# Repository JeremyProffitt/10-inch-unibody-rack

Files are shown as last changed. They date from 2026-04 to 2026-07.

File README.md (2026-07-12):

# 10-Inch Unibody Server Rack

A parametric, unibody 10-inch server rack designed to 3D print in a single piece on the **Bambu Labs H2D**. Prints front-face-down with **zero supports required**.

## Features

- **6U capacity** with standard EIA-310 mounting hole pattern
- **Prints in one piece** - no assembly required
- **No supports needed** - all geometry is self-supporting when printed face-down
- **Rounded exterior edges** for clean aesthetics and handling comfort
- **M6 nut traps** with diamond bevels for captive hardware
- **Grip bars** and filleted handle cutouts for comfortable carrying
- **Open back** for ventilation and cable management
- **Parametric design** - easily adjust rack units, depth, wall thickness
- **LCD + Raspberry Pi cases** in single/dual landscape and portrait layouts
- **Parametric viewing angle** with enclosure depth derived from the chosen angle

## Designs

### Just a Rack (6U)

| Front View | Rear View |
|---|---|
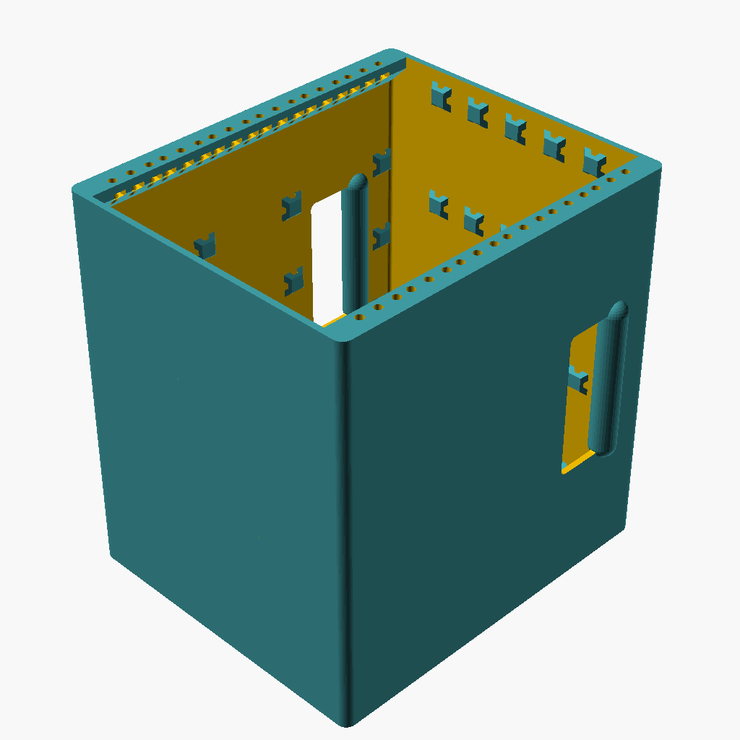
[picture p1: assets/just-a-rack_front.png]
Front
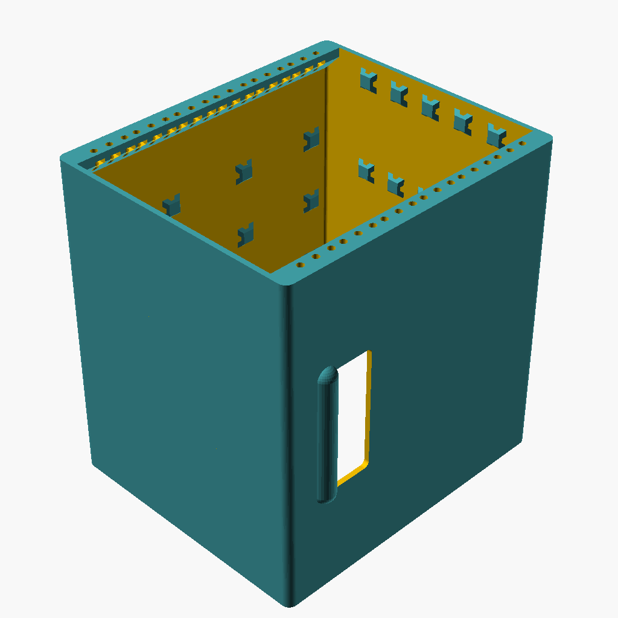
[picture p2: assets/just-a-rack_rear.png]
Rear
|  |  |

Unibody 6U 10-inch server rack with M6 nut traps, 18mm grip bars, filleted handle cutouts, and 30mm deep mounting rails. Prints support-free on the Bambu Labs H2D.

**Download STL**: [just-a-rack.stl](https://github.com/JeremyProffitt/10-inch-unibody-rack/releases/latest/download/just-a-rack.stl)

### Just a Rack with Pocket (6U)

| Front View | Rear View |
|---|---|
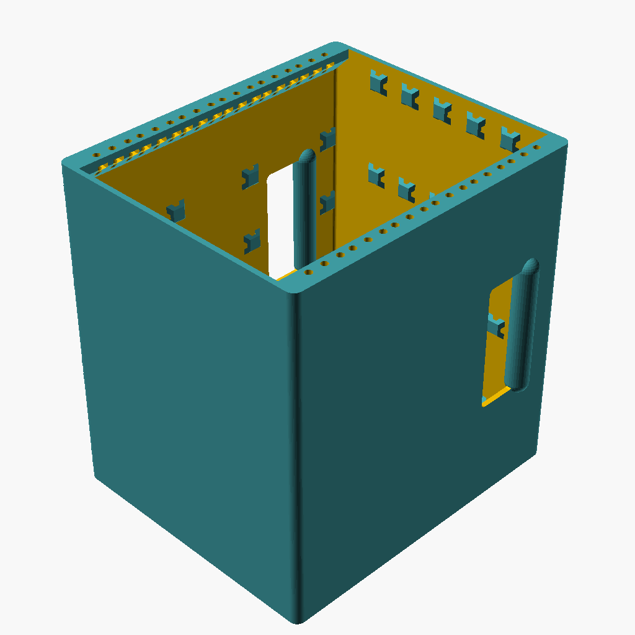
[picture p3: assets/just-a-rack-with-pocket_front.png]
Front
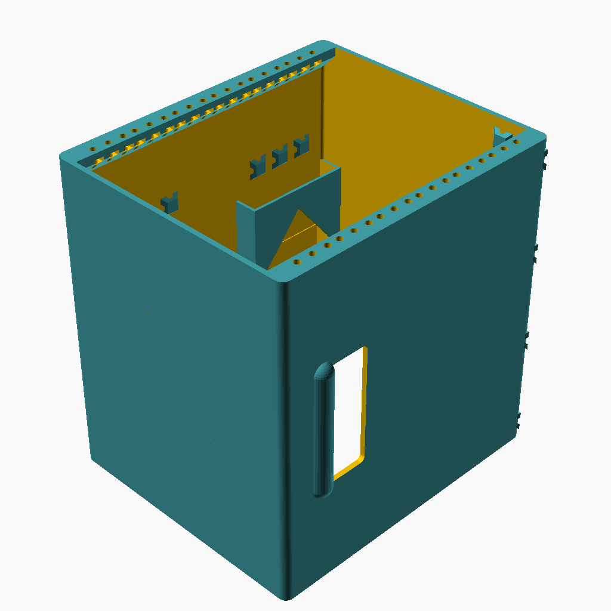
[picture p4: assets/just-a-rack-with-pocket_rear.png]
Rear
|  |  |

Same rack with a USW Flex Mini pocket on the right interior wall. Includes a 45-degree support ramp and triangular cable routing cutout for support-free printing.

**Download STL**: [just-a-rack-with-pocket.stl](https://github.com/JeremyProffitt/10-inch-unibody-rack/releases/latest/download/just-a-rack-with-pocket.stl)

### Rack with Cubbies (6U)

| Front View | Rear View |
|---|---|
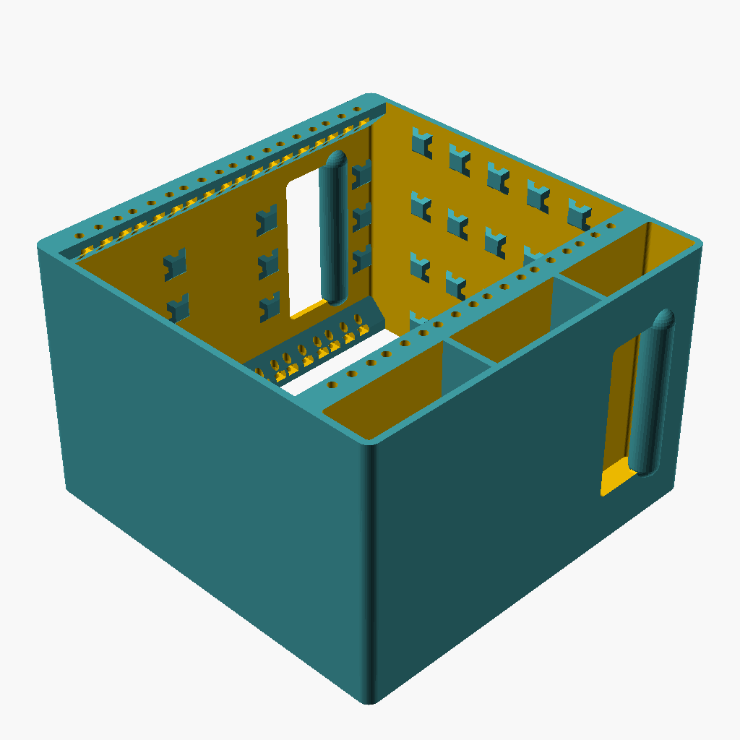
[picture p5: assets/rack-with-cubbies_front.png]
Front
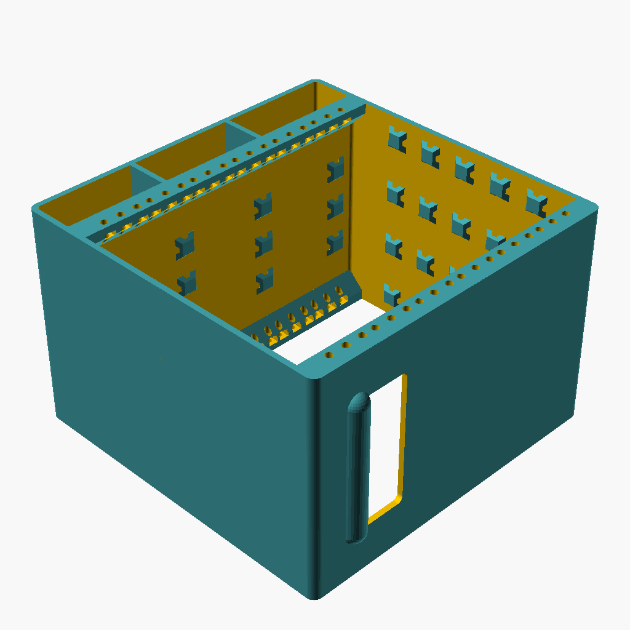
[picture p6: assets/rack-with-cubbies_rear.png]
Rear
|  |  |

Same rack with a 55mm cubby extension on the right side featuring horizontal shelves every 4 inches for accessory storage.

**Download STL**: [rack-with-cubbies.stl](https://github.com/JeremyProffitt/10-inch-unibody-rack/releases/latest/download/rack-with-cubbies.stl)

### Rack with Cubbies and Pocket (6U)

| Front View | Rear View |
|---|---|
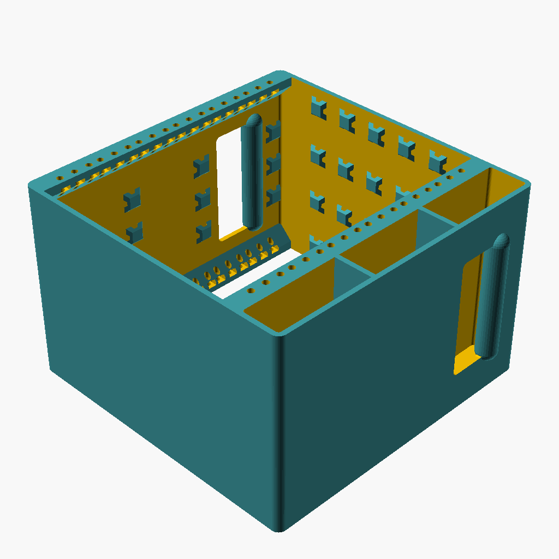
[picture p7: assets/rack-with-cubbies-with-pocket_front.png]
Front
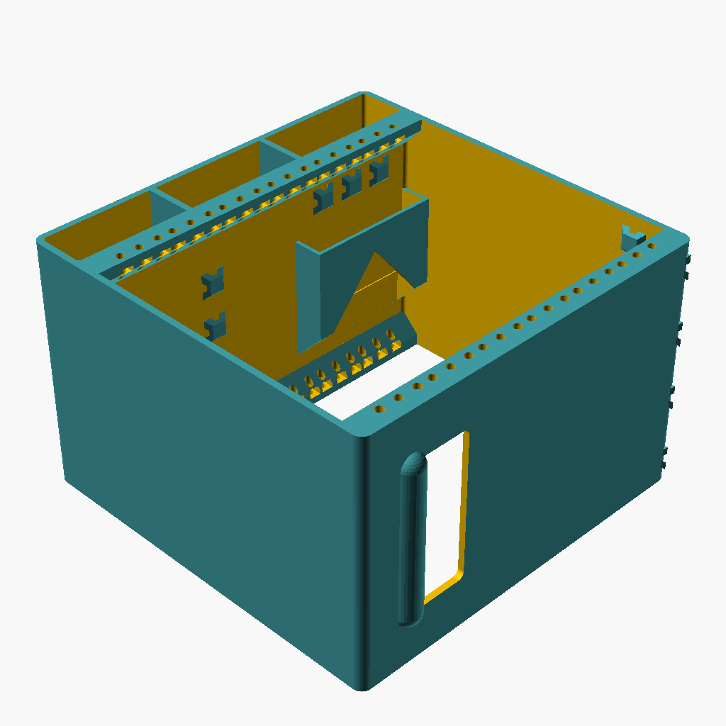
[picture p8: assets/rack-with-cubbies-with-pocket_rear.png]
Rear
|  |  |

Cubby rack with a USW Flex Mini pocket on the divider wall between the rack interior and cubbies. Combines storage cubbies with the built-in switch pocket.

**Download STL**: [rack-with-cubbies-with-pocket.stl](https://github.com/JeremyProffitt/10-inch-unibody-rack/releases/latest/download/rack-with-cubbies-with-pocket.stl)

### Just a Rack Short (6U)

| Front View | Rear View |
|---|---|
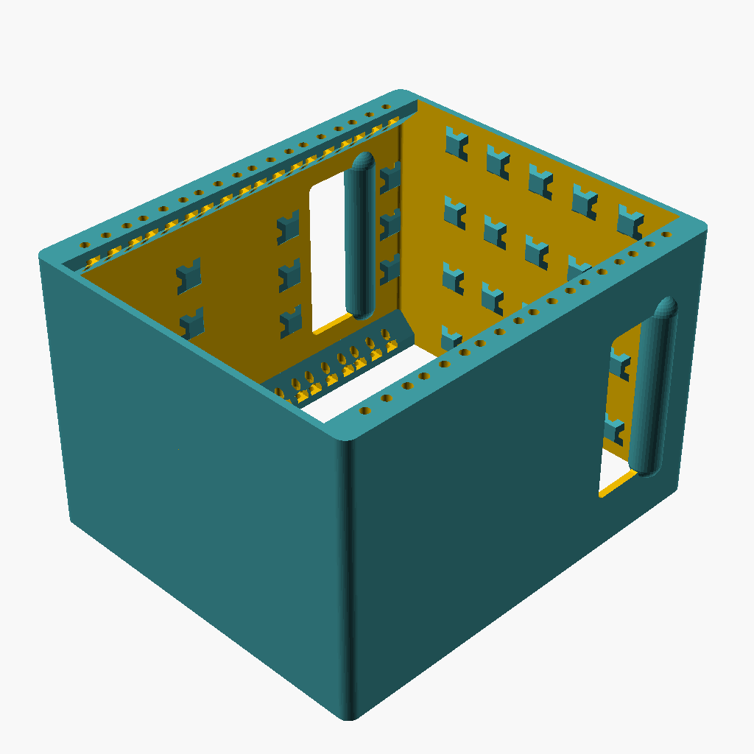
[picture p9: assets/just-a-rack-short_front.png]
Front
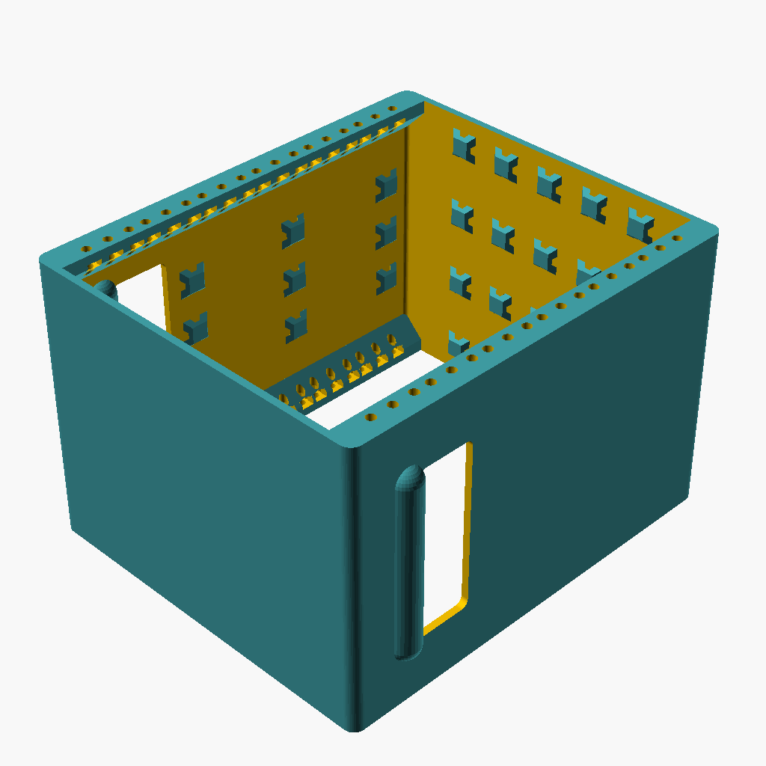
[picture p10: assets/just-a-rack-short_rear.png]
Rear
|  |  |

Shorter-depth variant of the standard unibody rack. Same M6 nut traps, grip bars, and handle cutouts as the full rack, but with a reduced front-to-back depth for locations with less clearance.

**Download STL**: [just-a-rack-short.stl](https://github.com/JeremyProffitt/10-inch-unibody-rack/releases/latest/download/just-a-rack-short.stl)

### Just a Rack with Pocket Short (6U)

| Front View | Rear View |
|---|---|
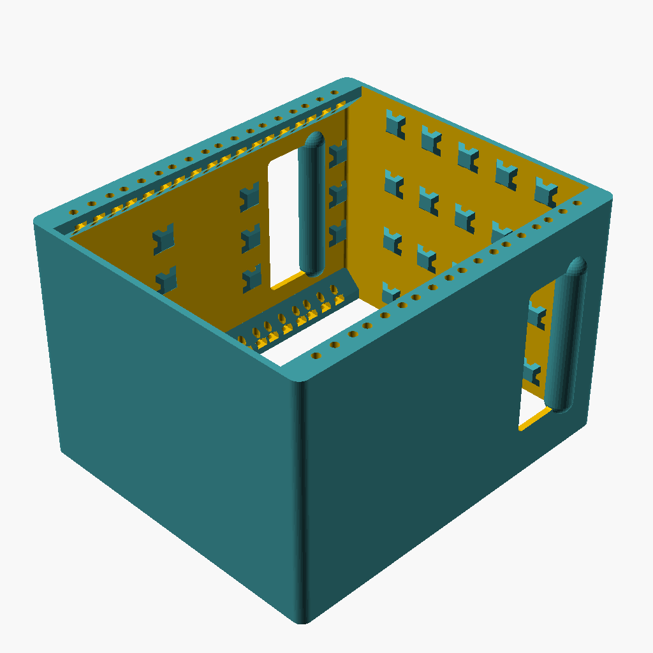
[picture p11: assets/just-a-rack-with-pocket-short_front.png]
Front
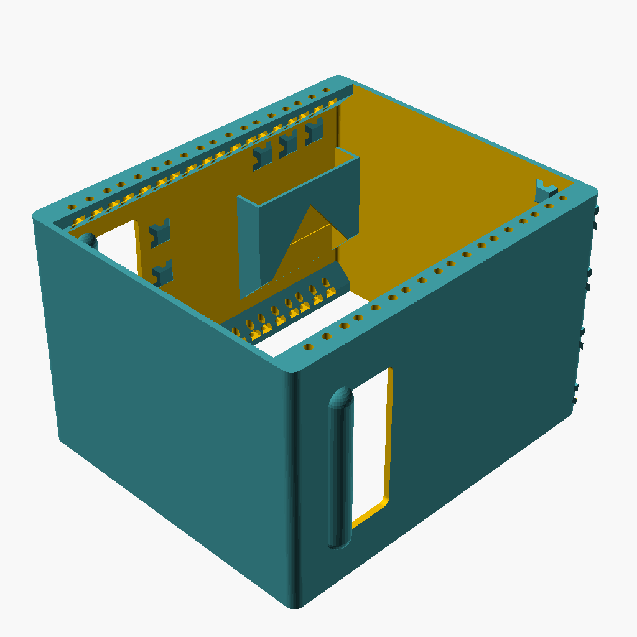
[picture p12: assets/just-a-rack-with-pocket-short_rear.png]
Rear
|  |  |

Short-depth rack body with the built-in USW Flex Mini pocket on the right interior wall. Combines the compact depth of the short variant with the integrated switch storage of the pocket variant.

**Download STL**: [just-a-rack-with-pocket-short.stl](https://github.com/JeremyProffitt/10-inch-unibody-rack/releases/latest/download/just-a-rack-with-pocket-short.stl)

### Waveshare 7-Inch LCD Panel

| Front View | Rear View |
|---|---|
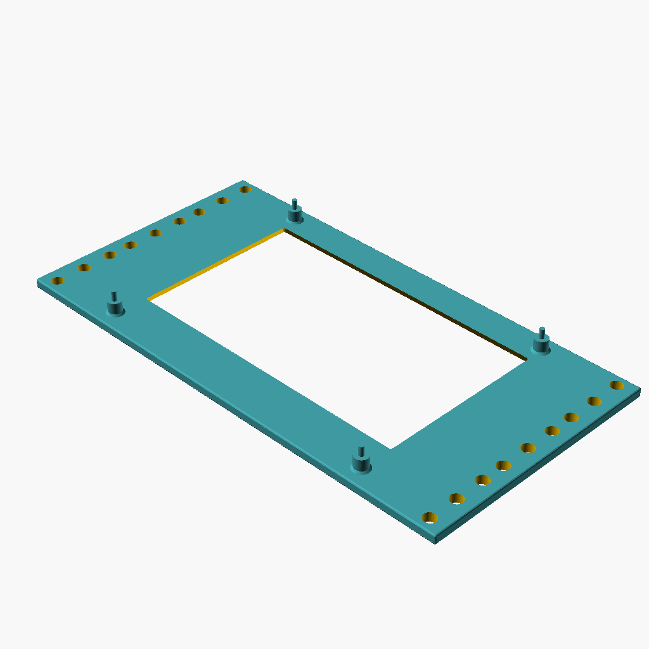
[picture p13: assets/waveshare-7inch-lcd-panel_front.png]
Front
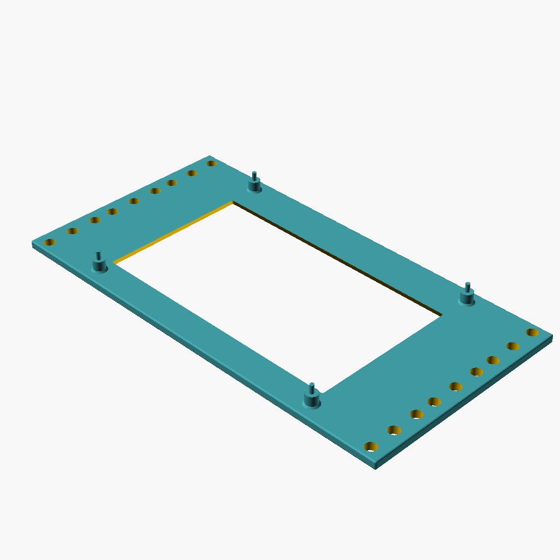
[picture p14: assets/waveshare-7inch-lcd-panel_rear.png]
Rear
|  |  |

Panel mount for the [Waveshare 7-inch LCD Display (Model B)](waveshare-7inch-lcd-display-b.md). Fits into a standard 10-inch rack panel slot, turning the LCD into a rack-mounted display.

**Documentation**: [waveshare-7inch-lcd-display-b.md](waveshare-7inch-lcd-display-b.md)

**Download STL**: [waveshare-7inch-lcd-panel.stl](https://github.com/JeremyProffitt/10-inch-unibody-rack/releases/latest/download/waveshare-7inch-lcd-panel.stl)

### Waveshare LCD + Pi Case - Landscape

| Front View | Rear View |
|---|---|
| Front | Rear |

Closed landscape enclosure with a solid-bottom Pi tray, removable LCD lid, 25.4 mm internal connector service region, five localized 10 mm cable passages, and a parametric 35-degree display plane.

**Documentation**: [waveshare-7inch-lcd-case-landscape.md](waveshare-7inch-lcd-case-landscape.md)

**Download Base STL**: [waveshare-7inch-lcd-case-landscape-base.stl](https://github.com/JeremyProffittOrg/10-inch-unibody-rack/releases/latest/download/waveshare-7inch-lcd-case-landscape-base.stl)

**Download Lid STL**: [waveshare-7inch-lcd-case-landscape-lid.stl](https://github.com/JeremyProffittOrg/10-inch-unibody-rack/releases/latest/download/waveshare-7inch-lcd-case-landscape-lid.stl)

### Waveshare LCD + Pi Case - Portrait

| Front View | Rear View |
|---|---|
| Front | Rear |

Closed portrait enclosure with the LCD in a removable cap, the Pi on a solid floor behind it, top/right internal service regions, and only small 10 mm cable passages through the walls.

**Documentation**: [waveshare-7inch-lcd-case-portrait.md](waveshare-7inch-lcd-case-portrait.md)

**Download Base STL**: [waveshare-7inch-lcd-case-portrait-base.stl](https://github.com/JeremyProffittOrg/10-inch-unibody-rack/releases/latest/download/waveshare-7inch-lcd-case-portrait-base.stl)

**Download Lid STL**: [waveshare-7inch-lcd-case-portrait-lid.stl](https://github.com/JeremyProffittOrg/10-inch-unibody-rack/releases/latest/download/waveshare-7inch-lcd-case-portrait-lid.stl)

### Waveshare LCD + Pi Case - Dual Portrait Side-by-Side

| Front View | Rear View |
|---|---|
| Front | Rear |

Two portrait LCDs in one removable lid above a solid-bottom Pi enclosure, with a shared internal cable region, continuous walls, localized 10 mm cord passages, and a 35-degree default angle.

**Documentation**: [waveshare-7inch-lcd-case-dual-portrait-side-by-side.md](waveshare-7inch-lcd-case-dual-portrait-side-by-side.md)

**Download Base STL**: [waveshare-7inch-lcd-case-dual-portrait-side-by-side-base.stl](https://github.com/JeremyProffittOrg/10-inch-unibody-rack/releases/latest/download/waveshare-7inch-lcd-case-dual-portrait-side-by-side-base.stl)

**Download Lid STL**: [waveshare-7inch-lcd-case-dual-portrait-side-by-side-lid.stl](https://github.com/JeremyProffittOrg/10-inch-unibody-rack/releases/latest/download/waveshare-7inch-lcd-case-dual-portrait-side-by-side-lid.stl)

### Waveshare LCD + Pi Case - Dual Landscape Stacked

| Front View | Rear View |
|---|---|
| Front | Rear |

Two stacked landscape LCDs in a removable lid above a closed solid-bottom Pi tray, with continuous walls, five small cable passages, right-side internal connector clearance, and angle-derived enclosure depth.

**Documentation**: [waveshare-7inch-lcd-case-dual-landscape-stacked.md](waveshare-7inch-lcd-case-dual-landscape-stacked.md)

**Download Base STL**: [waveshare-7inch-lcd-case-dual-landscape-stacked-base.stl](https://github.com/JeremyProffittOrg/10-inch-unibody-rack/releases/latest/download/waveshare-7inch-lcd-case-dual-landscape-stacked-base.stl)

**Download Lid STL**: [waveshare-7inch-lcd-case-dual-landscape-stacked-lid.stl](https://github.com/JeremyProffittOrg/10-inch-unibody-rack/releases/latest/download/waveshare-7inch-lcd-case-dual-landscape-stacked-lid.stl)

## Print Instructions

1. **Orientation**: Place the front face (Z=0) down on the build plate
2. **Supports**: None needed
3. **Material**: PLA, PETG, or ASA
4. **Infill**: 20-30%
5. **Layer Height**: 0.2mm
6. **Bed Adhesion**: Brim recommended (large footprint)

## Building Locally

### Linux/macOS

```bash
./build.sh
```

### Windows

```batch
generate.bat
```

Output files (STL and PNG) are generated in the `output/` directory.

## References

- [10-inch rack dimensions (Jeff Geerling - Project MINI RACK)](https://mini-rack.jeffgeerling.com/)
- [EIA-310 rack standard (Wikipedia)](https://en.wikipedia.org/wiki/19-inch_rack)
- [Bambu Labs H2D specifications](https://bambulab.com/en-us/h2d/tech-specs)

## License

Open source hardware. See individual files for details.

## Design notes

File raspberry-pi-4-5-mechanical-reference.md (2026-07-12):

# Raspberry Pi 4/5 Mechanical Reference

Mechanical reference for mounting a Raspberry Pi 4 Model B or Raspberry Pi 5
behind the Waveshare LCD cases in this repository. Both boards share the board
outline and four-hole mounting pattern used by the case generator.

## Shared Board Pattern

| Parameter | Value (mm) |
|---|---:|
| Board outline | 85.00 x 56.00 |
| Mounting-hole pitch | 58.00 x 49.00 |
| Mounting-hole nominal diameter | 2.70 |
| First-hole inset from left/bottom | 3.50 x 3.50 |

Hole centers from the board bottom-left corner are `(3.5, 3.5)`,
`(61.5, 3.5)`, `(3.5, 52.5)`, and `(61.5, 52.5)` mm.

## Port Edges

With the board component side facing the viewer and the GPIO header along the
top long edge:

- USB and Ethernet connectors occupy the right short edge.
- USB-C power and micro-HDMI video connectors occupy the bottom long edge.
- The microSD card is reached from the opposite short edge.

The closed cases keep this standard orientation on the solid floor:
USB/Ethernet faces the right wall, while power and micro-HDMI face the front
wall. Cable cords drop into 10 mm open-top wall notches before the lid is fitted,
so plug shells remain inside and do not need to pass through a drilled hole.

## Mounting Notes

- The printed bosses use 2.20 mm blind pilot holes for M2.5 self-tapping screws.
- The board plane is 14.00 mm behind the case front, leaving 9.00 mm below it.
- Removing the lid provides service access to GPIO, microSD, ports, and cooler.
- The enclosure is closed; confirm the selected Pi load and cooler do not require
  additional ventilation before long unattended operation.
- Verify an installed HAT, active cooler, or unusually large plug against the
  x-ray render before committing to a full-size print.

## Sources

- [Raspberry Pi 4 Model B mechanical drawing](https://pip.raspberrypi.com/categories/559-mechanical)
- [Raspberry Pi 5 mechanical drawing](https://datasheets.raspberrypi.com/rpi5/raspberry-pi-5-mechanical-drawing.pdf)
- [Raspberry Pi hardware documentation](https://www.raspberrypi.com/documentation/computers/raspberry-pi.html#schematics-and-mechanical-drawings)

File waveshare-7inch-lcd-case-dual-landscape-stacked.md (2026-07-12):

# Waveshare 7-Inch LCD Case - Dual Landscape Stacked

## Overview

Closed enclosure with two landscape LCDs stacked vertically in a removable lid.
One Raspberry Pi 4/5 mounts to the solid floor behind the lid. Both LCDs retain
their right-side internal connector clearance; cables leave through small 10 mm
U-notches rather than open wall sections.

The closed LCD plane defaults to 35 degrees above the table. Editing the angle
regenerates the base footprint, rear height, and lid-to-wall clearance.

## Dimensions

| Parameter | Default | Notes |
|---|---:|---|
| Two-LCD panel region | 284.40 x 279.96 mm | Stacked cells + right service |
| Base print envelope | 284.40 x 229.33 x 215.58 mm | W x table depth x rear height |
| Lid print envelope | 289.20 x 284.76 x 11.70 mm | Separate face-down part |
| LCD angle | 35 degrees | Above tabletop |
| Base front height | 55.00 mm | Closed electronics clearance |
| Solid floor / walls / lid | 5.00 / 5.00 / 5.00 mm | Complete enclosure surfaces |
| Lid side rails / clearance | 2.00 x 4.00 / 0.40 mm | Rail dimensions / per side |
| Right extension | 30.40 mm | 25.40 mm clear + wall |
| Inter-panel gap | 5.00 mm | Solid lid separator |
| Cable passages | 5 x 10.00 x 12.00 mm | Count x width x depth |
| Each landscape window | 156.00 x 89.00 mm | Existing opening |
| Each LCD PCB/module | 164.90 x 124.27 x 1.60 / 8.30 mm | PCB / total depth |
| Each hole pitch/diameter | 156.90 x 114.96 / 3.25 mm | Four M3 holes |
| LCD boss/counterbore | 7.00 x 6.70 / 5.00 x 2.00 mm | Per-display hardware |
| Pi mounts | 1 | One floor-mounted Pi 4/5 |
| Pi board/hole pitch | 85.00 x 56.00 / 58.00 x 49.00 mm | Shared pattern |
| Pi standoff/pilot | 7.00 x 9.00 / 2.20 x 7.00 mm | Boss / M2.5 pilot |
| Pi component allowance | 18.00 mm | Above board |
| Printer limit | 325 x 320 x 325 mm | Both parts fit H2D |

## Cross-Sections

### Front View - Lid

```text
+---------------------------------------------+
|    o +---------------------------+ o        |
|      |       upper LCD           |          |
|    o +---------------------------+ o        |
|                                             |
|    o +---------------------------+ o        |
|      |       lower LCD           |          |
|    o +---------------------------+ o        |
+---------------------------------------------+
```

### Top View - Base With Lid Removed

```text
+=============================================+  rear wall
|                                             |
|                SOLID BOTTOM                 |
|                            +--------------+ |
|                            | Raspberry Pi |>|  two right notches
|                            +--------------+ |
+======================= U====U====U ==========  front wall
```

### Side View - Closed

```text
rear 215.58  +--------------------------------+  stacked LCD lid
             |                               /
             |      Pi behind LCDs          /  35 degrees
front 55.00  +-----------------------------/
             +=============================+  solid floor
             <------ 229.33 table depth --->
```

## Components

| Component | Position / Bounding Box | Connection |
|---|---|---|
| Solid base | `[0,0,0]` to `[284.40,229.33,215.58]` | Floor-down closed tray |
| Pi bosses | Bottom-right base floor | Pi behind both LCDs |
| Continuous walls | Full base perimeter | Sloped lid support |
| Stacked lid | `[0,0,0]` to `[289.20,284.76,11.70]` when printed | Holds both LCDs |
| LCD bosses | Eight on lid underside | Four M3 per display |
| Cable passages | Five 10 mm capped U-notches | No broad wall cutouts |

## Print And Assembly

1. Print the base on its solid floor and the lid LCD-front-down.
2. Mount one Pi to the floor bosses with M2.5 screws.
3. Plug in Pi cables and lay their cords into the 10 mm wall notches.
4. Install both landscape LCDs in the lid with four M3 fasteners each.
5. Route the LCD connectors inside the right service region, rest the lid plate
   on the complete rim, and press its outside rails over the side walls.

Use a powered distribution solution sized for two LCDs. See
[LCD hardware reference](waveshare-7inch-lcd-display-b.md) and
[Pi mechanical reference](raspberry-pi-4-5-mechanical-reference.md).

## Changelog

- 2026-07-12: Rebuilt as a closed stacked enclosure with solid base and lid.

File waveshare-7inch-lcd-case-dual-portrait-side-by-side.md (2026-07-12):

# Waveshare 7-Inch LCD Case - Dual Portrait Side-by-Side

## Overview

Closed enclosure with two portrait LCDs in one removable lid and one Raspberry
Pi 4/5 mounted horizontally to the solid base floor behind them. Both rotated
LCD connector edges face the shared top service region. The base is a complete
tray with only five localized 10 mm cable U-notches.

The default 35-degree LCD plane is adjustable in the SCAD file. Base footprint,
rear wall height, lid border clearance, and closed assembly all update from that
single parameter.

## Dimensions

| Parameter | Default | Notes |
|---|---:|---|
| Two-LCD panel region | 310.36 x 284.40 mm | Two portrait cells + services |
| Base print envelope | 310.36 x 232.97 x 218.13 mm | W x table depth x rear height |
| Lid print envelope | 315.16 x 289.20 x 11.70 mm | Separate face-down part |
| LCD angle | 35 degrees | Above tabletop |
| Base front height | 55.00 mm | Closed electronics clearance |
| Solid floor / walls / lid | 5.00 / 5.00 / 5.00 mm | Complete enclosure surfaces |
| Lid side rails / clearance | 2.00 x 4.00 / 0.40 mm | Rail dimensions / per side |
| Right/top extensions | 30.40 / 30.40 mm | 25.40 mm clear + wall |
| Inter-panel gap | 5.00 mm | Solid lid separator |
| Cable passages | 5 x 10.00 x 12.00 mm | Count x width x depth |
| Each portrait window | 89.00 x 156.00 mm | Rotated existing opening |
| Each LCD PCB/module | 164.90 x 124.27 x 1.60 / 8.30 mm | PCB / total depth |
| Each portrait hole pitch | 114.96 x 156.90 mm | Four 3.25 mm M3 holes |
| LCD boss/counterbore | 7.00 x 6.70 / 5.00 x 2.00 mm | Per-display hardware |
| Pi mounts | 1 | One floor-mounted Pi 4/5 |
| Pi board/hole pitch | 85.00 x 56.00 / 58.00 x 49.00 mm | Shared pattern |
| Pi standoff/pilot | 7.00 x 9.00 / 2.20 x 7.00 mm | Boss / M2.5 pilot |
| Pi component allowance | 18.00 mm | Above board |
| Printer limit | 325 x 320 x 325 mm | Both parts fit H2D |

## Cross-Sections

### Front View - Lid

```text
+--------------------------------------------------+
|          shared top connector service            |
|   o +---------+ o    o +---------+ o             |
|     |portrait |        |portrait |               |
|   o +---------+ o    o +---------+ o             |
+--------------------------------------------------+
              removable dual-LCD lid
```

### Top View - Base With Lid Removed

```text
+==================================================+  rear wall
|                                                  |
|                 SOLID BOTTOM                     |
|                               +---------------+  |
|                               | Raspberry Pi  |->|  10 mm cord notches
|                               +---------------+  |
+========================== U====U====U ============  front wall
```

### Side View - Closed

```text
rear 218.13  +----------------------------------+  35-degree LCD lid
             |                                 /
             |      Pi behind both LCDs       /
front 55.00  +-------------------------------/
             +===============================+  solid floor
             <------- 232.97 table depth ---->
```

## Components

| Component | Position / Bounding Box | Connection |
|---|---|---|
| Solid base | `[0,0,0]` to `[310.36,232.97,218.13]` | One floor-down tray |
| Pi bosses | Bottom-right base floor | One Pi behind both LCDs |
| Base walls | Continuous perimeter | Supports sloped lid |
| Dual lid | `[0,0,0]` to `[315.16,289.20,11.70]` when printed | Holds both LCDs |
| LCD bosses | Eight total on lid underside | Four M3 per display |
| Cable passages | Five 10 mm capped U-notches | Cords installed before lid |

## Print And Assembly

1. Print the solid base floor-down and the dual-LCD lid face-down.
2. Mount one Pi to the base bosses with M2.5 screws.
3. Connect and route cables, laying their cords into the five 10 mm notches.
4. Mount both portrait LCDs to the lid with four M3 fasteners each.
5. Route both LCD cable sets through the shared internal top service region.
6. Rest the lid plate on the complete rim and press its outside side rails over
   the left/right walls.

Use a powered distribution solution sized for two LCDs. See
[LCD hardware reference](waveshare-7inch-lcd-display-b.md) and
[Pi mechanical reference](raspberry-pi-4-5-mechanical-reference.md).

## Changelog

- 2026-07-12: Rebuilt as a closed dual-portrait enclosure with solid base.

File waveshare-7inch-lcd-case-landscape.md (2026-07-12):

# Waveshare 7-Inch LCD Case - Landscape

## Overview

Closed two-part enclosure for one landscape Waveshare LCD and one Raspberry Pi
4/5. The removable lid contains the LCD opening, M3 holes, and mounting bosses.
The Pi mounts horizontally to bosses on the solid base floor, behind the LCD.

The base has four continuous walls. Three 10 mm front notches and two 10 mm
right notches carry cable cords; the lid plate caps the front notches and the
right locator rail has matching reliefs.
There are no broad wall openings. The default LCD angle is 35 degrees above the
table, and changing `lcd_angle_from_table_deg` recalculates the base footprint,
rear height, and LCD-to-wall clearance.

## Dimensions

| Parameter | Default | Notes |
|---|---:|---|
| LCD panel region | 284.40 x 137.48 mm | Includes right connector extension |
| Base print envelope | 284.40 x 112.62 x 133.85 mm | W x table depth x rear height |
| Lid print envelope | 289.20 x 142.28 x 11.70 mm | Separate face-down part |
| LCD angle | 35 degrees | Above tabletop |
| Base front height | 55.00 mm | Minimum closed electronics depth |
| Solid floor | 5.00 mm | Full base footprint |
| Wall thickness | 5.00 mm | Four continuous walls |
| Lid thickness | 5.00 mm | LCD faceplate |
| Lid side rails | 2.00 x 4.00 mm | Thickness x depth outside side walls |
| Lid fit clearance | 0.40 mm per side | Removable outside cap |
| Right extension | 30.40 mm | 25.40 mm clear + 5.00 mm wall |
| Cable passages | 5 x 10.00 mm | Three front, two right U-notches |
| Cable notch depth | 12.00 mm | Open at base rim; capped by lid |
| LCD window, back/front | 156.00 x 89.00 / 162.00 x 95.00 mm | Existing opening + bevel |
| LCD window offset | +1.00 X, +4.00 Y mm | Source panel coordinates |
| LCD PCB/module | 164.90 x 124.27 x 1.60 / 8.30 mm | PCB / total depth |
| LCD hole pitch/diameter | 156.90 x 114.96 / 3.25 mm | Four M3 holes |
| LCD boss | 7.00 x 6.70 mm | Diameter x length |
| LCD counterbore | 5.00 x 2.00 mm | Diameter x depth |
| Pi board/hole pitch | 85.00 x 56.00 / 58.00 x 49.00 mm | Pi 4/5 shared pattern |
| Pi standoff | 7.00 x 9.00 mm | Diameter x height on floor |
| Pi pilot hole | 2.20 x 7.00 mm | M2.5 self-tapping pilot |
| Pi component allowance | 18.00 mm | Above board |
| Printer limit | 325 x 320 x 325 mm | H2D single-nozzle volume |

## Cross-Sections

### Front View - Lid

```text
<--------------------- 289.20 --------------------->
+---------------------------------------------------+
|          o +-------------------------+ o          |
|            |     LANDSCAPE LCD       |            |
|          o +-------------------------+ o          |
+---------------------------------------------------+
       removable lid; LCD hardware on underside
```

### Top View - Base With Lid Removed

```text
+===================================================+  rear wall
|                                                   |
|             SOLID BOTTOM FLOOR                    |
|                                  +-------------+  |
|                                  | Raspberry Pi|->|  two 10 mm right notches
|                                  +-------------+  |
+============================= U==U==U ==============  front wall
                              power / video cords
```

### Side View - Closed

```text
                      lid / LCD plane (35 degrees)
rear 133.85  +-----------------------------------+
             |                                  /
             |       Pi behind LCD             /
front 55.00  +--------------------------------/
             +================================+  solid 5 mm floor
             <--------- 112.62 table depth -->
```

## Components

| Component | Position / Bounding Box | Connection |
|---|---|---|
| Solid base | `[0,0,0]` to `[284.40,112.62,133.85]` | Floor-down printable part |
| Pi bosses | Bottom-right floor region, Z `5.00..14.00` | Pi lies flat behind LCD |
| Base walls | Complete footprint perimeter | Sloped top receives lid |
| Lid | `[0,0,0]` to `[289.20,142.28,11.70]` in print orientation | Plate plus outside side rails |
| LCD bosses | Lid underside, Z `5.00..11.70` in print orientation | Four M3 mounts |
| Cable passages | Three front and two right 10 mm U-notches | Cord drops in before lid |

## Print And Assembly

1. Export and print `-base.stl` floor-down without supports.
2. Export and print `-lid.stl` LCD-front-down without supports.
3. Mount the Pi to the base bosses with M2.5 self-tapping screws.
4. Plug cables into the Pi, then drop their cords into the 10 mm U-notches.
   Plug shells remain inside and do not need to pass through the openings.
5. Mount the LCD to the lid with four M3 fasteners and route its right-edge
   HDMI and micro-USB leads inside the 25.4 mm service region.
6. Rest the lid plate on the complete wall rim and press its two outside side
   rails over the left/right walls.

See [LCD hardware reference](waveshare-7inch-lcd-display-b.md) and
[Pi mechanical reference](raspberry-pi-4-5-mechanical-reference.md).

## Changelog

- 2026-07-12: Rebuilt as a closed solid-bottom base with removable LCD lid.

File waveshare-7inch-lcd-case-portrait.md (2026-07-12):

# Waveshare 7-Inch LCD Case - Portrait

## Overview

Closed two-part enclosure for one portrait Waveshare LCD and a floor-mounted
Raspberry Pi 4/5. The LCD and its M3 hardware are entirely in the removable lid;
the Pi is always behind it on the solid base. Rotating the LCD counter-clockwise
moves its connector edge to the top, so the lid includes a 25.4 mm top service
region while retaining the requested right extension.

All four base walls are continuous except five localized 10 mm cable U-notches.
The default 35-degree angle is parametric and regenerates the base depth and rear
height.

## Dimensions

| Parameter | Default | Notes |
|---|---:|---|
| LCD panel region | 167.88 x 284.40 mm | Portrait cell + right/top service |
| Base print envelope | 167.88 x 232.97 x 218.13 mm | W x table depth x rear height |
| Lid print envelope | 172.68 x 289.20 x 11.70 mm | Separate face-down part |
| LCD angle | 35 degrees | Above tabletop |
| Base front height | 55.00 mm | Electronics clearance |
| Solid floor / walls / lid | 5.00 / 5.00 / 5.00 mm | Full bottom and shell |
| Lid side rails / clearance | 2.00 x 4.00 / 0.40 mm | Rail thickness/depth / per side |
| Right extension | 30.40 mm | 25.40 mm clear + wall |
| Top extension | 30.40 mm | Rotated LCD connector service |
| Cable passages | 5 x 10.00 x 12.00 mm | Count x width x depth |
| Portrait LCD window | 89.00 x 156.00 mm | Rotated existing back opening |
| Source window offset | +1.00 X, +4.00 Y mm | Before rotation |
| LCD PCB/module | 164.90 x 124.27 x 1.60 / 8.30 mm | PCB / total depth |
| Portrait hole pitch/diameter | 114.96 x 156.90 / 3.25 mm | Four M3 holes |
| LCD boss/counterbore | 7.00 x 6.70 / 5.00 x 2.00 mm | Boss / front recess |
| Pi board/hole pitch | 85.00 x 56.00 / 58.00 x 49.00 mm | Pi 4/5 shared pattern |
| Pi standoff/pilot | 7.00 x 9.00 / 2.20 x 7.00 mm | Boss / M2.5 pilot |
| Pi component allowance | 18.00 mm | Above board |
| Printer limit | 325 x 320 x 325 mm | H2D single-nozzle volume |

## Cross-Sections

### Front View - Lid

```text
+---------------------------+  top cable service region
|                           |
|       o +---------+ o     |
|         |         |       |
|         | PORTRAIT|       |
|         |   LCD   |       |
|       o +---------+ o     |
+---------------------------+
       removable LCD lid
```

### Top View - Base With Lid Removed

```text
+===========================+  rear wall
|                           |
|      SOLID BOTTOM         |
|          +-------------+  |
|          | Raspberry Pi|->|  two 10 mm right notches
|          +-------------+  |
+===== U======U======U ======  front cable notches
```

### Side View - Closed

```text
rear 218.13  +-----------------------------+  LCD lid at 35 degrees
             |                            /
             |       Pi behind LCD       /
front 55.00  +--------------------------/
             +==========================+  solid floor
             <---- 232.97 table depth -->
```

## Components

| Component | Position / Bounding Box | Connection |
|---|---|---|
| Solid base | `[0,0,0]` to `[167.88,232.97,218.13]` | Floor-down part |
| Pi bosses | Bottom-right floor, Z `5.00..14.00` | Pi behind portrait lid |
| Continuous walls | Full base perimeter | Sloped cap rim |
| LCD lid | `[0,0,0]` to `[172.68,289.20,11.70]` when printed | Face-down part |
| LCD bosses | Four on lid underside | M3 LCD mounting |
| Cable notches | Three front, two right | 10 mm capped passages |

## Print And Assembly

1. Print the base floor-down and the lid LCD-front-down without supports.
2. Fasten the Pi to the base floor bosses with M2.5 screws.
3. Connect Pi power, video, and USB leads; place only the cable cords into the
   10 mm U-notches before closing the lid.
4. Fasten the portrait LCD to the lid with four M3 screws. Route LCD cables
   through the internal top service region.
5. Rest the lid on the complete rim and press its outside side rails over the
   left/right walls.

See [LCD hardware reference](waveshare-7inch-lcd-display-b.md) and
[Pi mechanical reference](raspberry-pi-4-5-mechanical-reference.md).

## Changelog

- 2026-07-12: Rebuilt as a closed portrait enclosure with separate lid/base.

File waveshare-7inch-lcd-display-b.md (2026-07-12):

# Waveshare 7inch HDMI LCD (B) — Reference

Research reference for the **Waveshare 7inch HDMI LCD (B)** — a 7" capacitive-touch HDMI display (800x480) intended to be integrated as a rack-mounted display for this project.

All dimensions are taken directly from the official Waveshare mechanical drawing (see Sources). Use these values as the authoritative source when designing any mount, case, or bezel for this display.

---

## Identification

| Field | Value |
|---|---|
| Product name | 7inch HDMI LCD (B) |
| Vendor | Waveshare |
| Panel resolution | 800 x 480 px |
| Panel type | Capacitive touch, HDMI input |
| Rev (current) | 2.1 (driver-free, HID-compliant) |

---

## Board dimensions (PCB, back view)

| Parameter | Value (mm) |
|---|---|
| PCB outline width | 164.90 |
| PCB outline height | 124.27 |
| Mounting hole spacing, X (center-to-center) | 156.90 |
| Mounting hole spacing, Y (center-to-center) | 114.96 |
| Mounting hole diameter | Ø3.25 (4 holes, M3 clearance, snug) |
| Hole inset from left/right edge | 4.00 |
| Hole inset from top/bottom edge | 4.655 |

### Mounting hole centers (from PCB bottom-left corner)

| Corner | X (mm) | Y (mm) |
|---|---|---|
| Bottom-Left | 4.00 | 4.655 |
| Bottom-Right | 160.90 | 4.655 |
| Top-Left | 4.00 | 119.615 |
| Top-Right | 160.90 | 119.615 |

---

## LCD glass / viewing area (front view)

| Parameter | Value (mm) | Notes |
|---|---|---|
| Lens OD (glass outline) | 164.28 x 99.17 | ±0.1 |
| Viewing Area (VA) | 154.58 x 86.42 | ±0.2, 800x480 px |
| VA offset inside lens (bottom) | 8.73 | Derived from lens/VA heights |
| VA offset inside lens (left) | 3.06 | |
| VA offset inside lens (top) | 4.02 | |

---

## Thickness (side view)

| Parameter | Value (mm) |
|---|---|
| Total module (PCB + glass + components) | 8.3 ±0.3 |
| PCB alone | 1.6 |

---

## Connectors (right edge when installed)

The official mechanical drawing is a **back view**, where the connectors appear
on the PCB's left edge. From the installed front/viewer side they are on the
**right edge**, matching the orientation used by the case designs.

That edge carries the following, from top to bottom in the back-view drawing:
- Full-size HDMI Type-A input (labeled "Display")
- Micro-USB (touch and power)
- 5V / GND test points
- Backlight on/off switch

### Connector centerlines

The official assembly drawing dimensions the connector/switch centerlines from
the PCB top edge. The source panel centers the PCB at Y=4.54..128.81 mm:

| Feature | Down from PCB top (mm) | Source-panel Y (mm) |
|---|---:|---:|
| HDMI Type-A center | 21.18 | 107.63 |
| Micro-USB center | 40.18 | 88.63 |
| Backlight switch center | 53.88 | 74.93 |

The cases reserve source-panel Y=70.00..122.00 mm for the connector envelope
and keep 25.40 mm of internal lid space beyond the connector edge. The
Raspberry Pi mounts separately to the solid base floor behind the LCD plane,
not in that lid region. These are clearance envelopes rather than exact
connector-body dimensions; verify unusually large straight plugs against the
physical display revision.

Any enclosure must provide at least **1 inch (25.4 mm) of clear cable space on
the installed right side**. Rotating the LCD 90 degrees counter-clockwise for
portrait use moves this physical connector edge to the installed top, so the
portrait cases provide a separate top chase while retaining the requested
right-side bay.

---

## ASCII diagrams

### Front view (glass / viewing area)

```
        <--------- 164.28 ---------->       (Lens OD)
        <-------- 154.58 --------->         (VA, 800x480 px)
     +---------------------------------+  ^
   ^ |  +---------------------------+  |  |
 4.02| |  |                           | |  |
   v | |  |    VIEWING AREA           | |  | 99.17 (Lens OD)
     | |  |    154.58 x 86.42 mm      | | 86.42 (VA)
     | |  |    (800 x 480 px)         | |  |
     | |  +---------------------------+ |  |
     | +----+------------------------+--+  v
     +------|-- 3.06
            v
```

### PCB back view with mounting holes

```
        <------------ 164.90 ------------>
        <--- 4.00 ---|<-- 156.90 -->|---->
     +--O-----------------------------O--+  ^
     |  |     (TL hole center)        |  |  |
     |  |                             |  |  |
     |  |    +---------------------+  |  |  |
     |  |    |                     |  |  |  | 124.27
     | HDMI  |     PCB features    |  |  |  | (PCB)
     | USB   |     (ICs, FFC)      |  | 114.96
     |  |    |                     |  |  |  |
     |  |    +---------------------+  |  |  |
     |  |                             |  |  |
     +--O-----------------------------O--+  v
      4.655  (BL hole center)  4.655 ^
```

---

## Usage notes for this project

- **Cable clearance**: Reserve at least 25.4 mm (1") beyond the installed right
  connector edge. The new cases provide 25.4 mm of clear space plus a 5 mm
  outer wall beyond the compatible 254 mm source-panel boundary.
- **Minimum rack height**: PCB is 124.27 mm tall. Fits in 3U (133.35 mm) with 9 mm margin, or more comfortably in 4U (177.8 mm).
- **Mounting screws**: 4 x M3, 8-10 mm long machine screws are compatible (Ø3.25 mm holes).
- **Print orientation**: Any case must support printing face-down with no supports per project conventions. The viewing window is a simple rectangular cutout; the PCB mounting bosses should be vertical in print.
- **LCD opening in bezel**: The vendor bezel-open dimension is
  `156.70 x 89.10 mm`; visible active area is `154.58 x 86.42 mm`. The existing
  rack panel and the four compatible case designs intentionally preserve the
  repository's earlier `156.00 x 89.00 mm` back opening with a 3 mm front
  bevel. Increase the shared case constants if exact vendor bezel-open size is
  preferred over compatibility with the existing panel geometry.

---

## Sources

- Waveshare Wiki — main product page: https://www.waveshare.com/wiki/7inch_HDMI_LCD_(B)
- Waveshare mechanical drawing (authoritative PCB + glass dimensions): https://files.waveshare.com/wiki/7inch%20HDMI%20LCD%20(B)/7inch%20HDMI%20LCD%20(B).pdf
- Waveshare LCD panel dimension drawing: https://files.waveshare.com/upload/3/34/7inch-hdmi-lcd-b-panel-dimension.pdf
- Waveshare STEP (3D CAD) model: https://files.waveshare.com/wiki/7inch%20HDMI%20LCD%20(B)/7inch%20HDMI%20LCD%20(B).stp
- Waveshare exterior size image: https://www.waveshare.com/img/devkit/LCD/7BP/Exterior-Size.jpg
- User manual PDF: https://www.waveshare.com/w/upload/1/19/7inch_HDMI_LCD_(B)_User_Manual.pdf

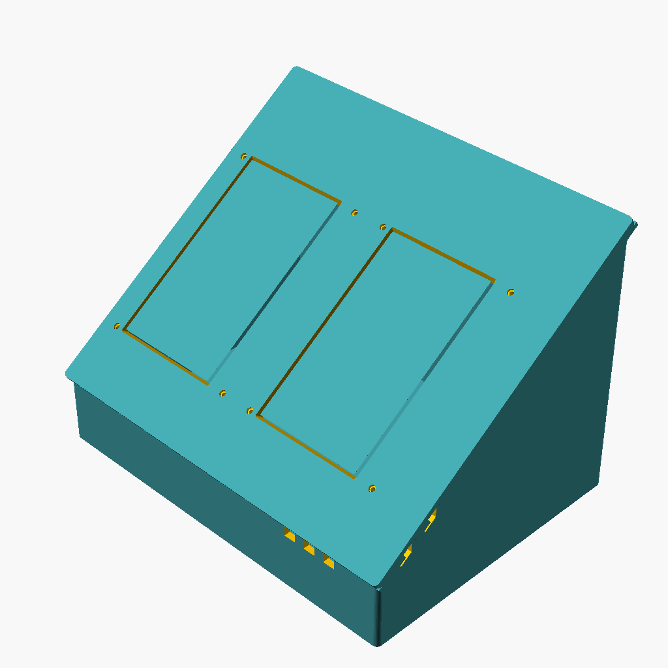
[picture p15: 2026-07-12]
assets/waveshare-7inch-lcd-case-dual-portrait-side-by-side_front.png

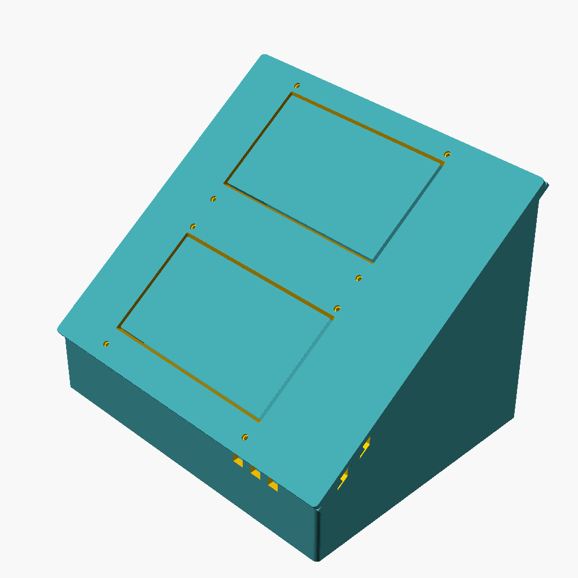
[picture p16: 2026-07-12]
assets/waveshare-7inch-lcd-case-dual-landscape-stacked_front.png

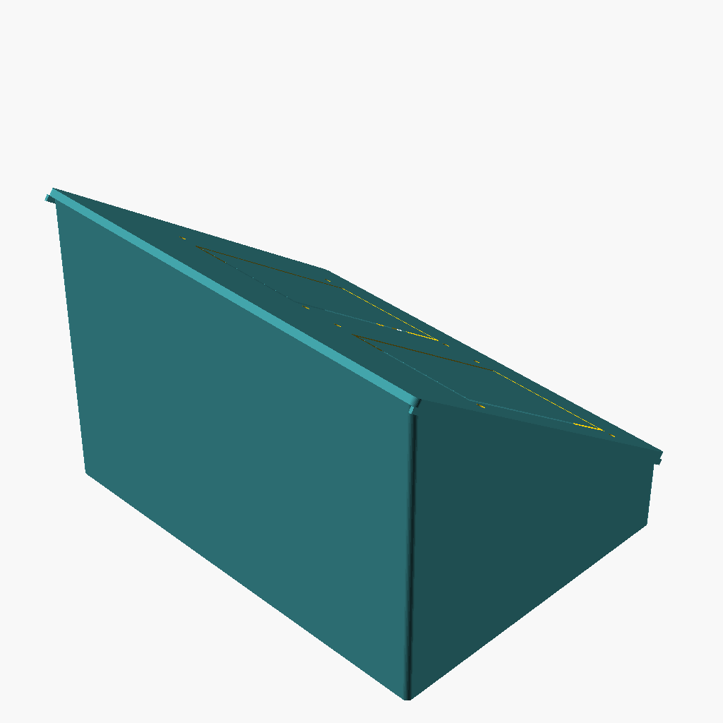
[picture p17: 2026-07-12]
assets/waveshare-7inch-lcd-case-dual-portrait-side-by-side_rear.png

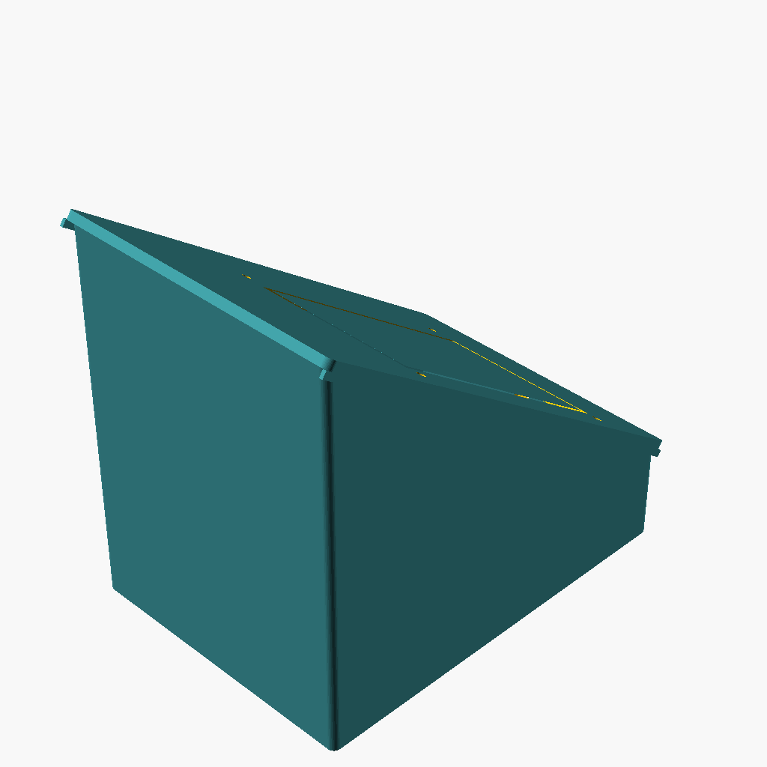
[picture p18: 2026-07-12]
assets/waveshare-7inch-lcd-case-portrait_rear.png

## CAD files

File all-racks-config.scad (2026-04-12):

/**
 * Shared Configuration and Modules for All Rack Designs
 *
 * Coordinate System (print orientation):
 *   X = Rack width  (positive = right when facing rack front)
 *   Y = Rack height (positive = up in use orientation; along bed Y in print)
 *   Z = Rack depth  (positive = toward back; upward in print orientation)
 *
 * Origin: Front-bottom-left corner of rack outer shell
 *
 * Print Orientation:
 *   Front face (Z=0) placed on build plate.
 *   All walls are vertical in print - zero supports required.
 *   Nut pocket bevels are self-supporting (pointed ceiling).
 *
 * Bambu Labs H2D Build Volume (single nozzle): 325 x 320 x 325 mm
 */

// =========================================
// DIMENSIONS (all values in millimeters)
// =========================================

// --- Printer Constraints (Bambu Labs H2D, single nozzle) ---
printer_max_x_mm = 325;
printer_max_y_mm = 320;
printer_max_z_mm = 325;

// --- 10-Inch Rack Standard (derived from IEC 60297 / EIA-310) ---
rack_panel_width_mm         = 254.0;     // 10" = total front panel width
rack_rail_to_rail_center_mm = 236.525;   // 9.312" mounting hole center-to-center
rack_rail_width_mm          = 15.875;    // 0.625" width of each mounting rail
rack_clear_opening_mm       = 222.25;    // 8.75" clear space between rail inner edges
rack_unit_height_mm         = 44.45;     // 1U = 1.75"

// Vertical hole pattern within each U (measured from bottom of each U)
rack_hole_offset_1_mm = 6.35;           // 0.25"
rack_hole_offset_2_mm = 22.225;         // 0.875"
rack_hole_offset_3_mm = 38.10;          // 1.50"

// --- Design Parameters ---
wall_thickness_mm      = 5.0;           // Wall thickness on all sides
rack_units             = 6;             // Number of rack units
rack_depth_mm          = 200.0;         // Total front-to-back depth
rail_depth_mm          = 25.0;          // How far mounting rails extend from front face
rail_margin_mm         = 16.65;         // Extra space above/below mounting holes
rail_bevel_mm          = rack_rail_width_mm; // 45-degree bevel full rail width on inner edge
mount_hole_diameter_mm = 6.5;           // Clearance hole for M6 / #12-24 screws
edge_radius_mm         = 8.0;           // Fillet radius on outer vertical edges

// --- M6 Nut Trap Parameters ---
enable_nut_traps        = true;         // Set false for simple through-holes only
nut_across_flats_mm     = 10.0;         // M6 hex nut across flats
nut_thickness_mm        = 5.0;          // M6 hex nut thickness
nut_tolerance_mm        = 0.3;          // Print clearance tolerance
nut_pocket_af_mm        = nut_across_flats_mm + nut_tolerance_mm;   // 10.3mm
nut_pocket_depth_mm     = nut_thickness_mm + nut_tolerance_mm;       // 5.3mm
nut_hex_od_mm           = nut_pocket_af_mm / cos(30);                // ~11.9mm across corners
nut_bevel_height_mm     = 1.0;          // V bevel height for printability
nut_z_start_mm          = 6.0;                                       // 6mm behind front face of rail
nut_slot_width_mm       = nut_pocket_af_mm;                          // 10.3mm

// Back rail nut trap Z position (mirrored from front)
back_rail_z_start_mm    = rack_depth_mm - rail_depth_mm;             // Where back rail begins
back_nut_z_start_mm     = rack_depth_mm - nut_z_start_mm - nut_pocket_depth_mm; // Mirrored pocket start

// --- Handle Cutouts (side walls, near top) ---
// Long axis runs along Z (depth), short axis along Y (height)
handle_slot_length_mm   = 120.0;        // Along Z (rack depth direction)
handle_slot_width_mm    = 42.0;         // Along Y (rack height direction)
handle_slot_radius_mm   = 5.0;          // Small rounded corners
handle_fillet_radius_mm = 2.0;          // Fillet on edges where handle meets wall exterior
handle_top_offset_mm    = 50.0;         // Distance from rack top to handle top edge
grip_bar_diameter_mm    = 21.6;         // Cylindrical grab bar at top of handle cutout

// --- Zip Tie Tower Parameters ---
zip_tower_base_mm       = 20.0;         // Base footprint (square)
zip_tower_top_mm        = 12.0;         // Flat top size (square)
zip_tower_height_mm     = 4.4;          // Tower height from wall surface
zip_tunnel_width_mm     = 8.0;          // Tunnel width
zip_tunnel_height_mm    = 2.4;          // Tunnel height
zip_cable_roof_mm       = 0.0;          // Tunnel starts at z=0 (bottom)

// --- Computed Dimensions ---
rack_height_mm      = rack_units * rack_unit_height_mm;                              // 266.7mm
outer_width_mm      = rack_panel_width_mm + 2 * wall_thickness_mm;                   // 264mm
outer_height_mm     = rack_height_mm + 2 * wall_thickness_mm + 2 * rail_margin_mm;   // 286.7mm
inner_height_mm     = outer_height_mm - 2 * wall_thickness_mm;                       // 276.7mm
inner_corner_radius_mm = max(0.1, edge_radius_mm - wall_thickness_mm);               // 3mm

// Mounting area Y bounds (holes only - rails extend full inner height)
mount_area_y_start_mm = wall_thickness_mm + rail_margin_mm;                          // 10mm
mount_area_y_end_mm   = mount_area_y_start_mm + rack_height_mm;                      // 276.7mm

// Mounting hole X positions (from outer left edge)
mount_hole_x_left_mm  = wall_thickness_mm +
    (rack_panel_width_mm - rack_rail_to_rail_center_mm) / 2;                         // ~13.74mm
mount_hole_x_right_mm = outer_width_mm - mount_hole_x_left_mm;                       // ~250.26mm

// Rail inner face X positions (facing rack interior)
rail_left_inner_x_mm  = wall_thickness_mm + rack_rail_width_mm;                      // 20.875mm
rail_right_inner_x_mm = outer_width_mm - wall_thickness_mm - rack_rail_width_mm;     // 243.125mm

// Handle position: 50mm from top of rack, centered along depth
handle_y_center_mm  = outer_height_mm - handle_top_offset_mm
                      - handle_slot_width_mm / 2;
handle_z_center_mm  = rack_depth_mm / 2;

// --- Print Fit Assertions (base rack) ---
assert(outer_width_mm <= printer_max_x_mm,
    str("Width ", outer_width_mm, "mm exceeds printer X=", printer_max_x_mm, "mm"));
assert(outer_height_mm <= printer_max_y_mm,
    str("Height ", outer_height_mm, "mm exceeds printer Y=", printer_max_y_mm, "mm"));
assert(rack_depth_mm <= printer_max_z_mm,
    str("Depth ", rack_depth_mm, "mm exceeds printer Z=", printer_max_z_mm, "mm"));

$fn = 48;

// =========================================
// SHARED MODULES
// =========================================

/**
 * Rounded Box
 *
 * Box with filleted edges along Z axis (vertical in print = no supports).
 * XY cross-section is a rounded rectangle.
 */
module rounded_box(w, h, d, r) {
    hull() {
        translate([r, r, 0])     cylinder(h = d, r = r);
        translate([w-r, r, 0])   cylinder(h = d, r = r);
        translate([r, h-r, 0])   cylinder(h = d, r = r);
        translate([w-r, h-r, 0]) cylinder(h = d, r = r);
    }
}

/**
 * Inner Cavity
 *
 * Interior void with rounded corners matching outer shell.
 * Extends through front and back (open both ends).
 */
module inner_cavity() {
    ir = inner_corner_radius_mm;
    translate([wall_thickness_mm, wall_thickness_mm, -1]) {
        hull() {
            translate([ir, ir, 0])
                cylinder(h = rack_depth_mm + 2, r = ir);
            translate([rack_panel_width_mm - ir, ir, 0])
                cylinder(h = rack_depth_mm + 2, r = ir);
            translate([ir, inner_height_mm - ir, 0])
                cylinder(h = rack_depth_mm + 2, r = ir);
            translate([rack_panel_width_mm - ir, inner_height_mm - ir, 0])
                cylinder(h = rack_depth_mm + 2, r = ir);
        }
    }
}
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

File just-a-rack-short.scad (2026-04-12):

/**
 * 10-Inch Unibody Server Rack (6U) - "Just a Rack"
 * Prints in one piece on Bambu Labs H2D - front face down, no supports
 *
 * Bambu Labs H2D Build Volume (single nozzle): 325 x 320 x 325 mm
 * This model footprint: 264 x 310 mm (fits within 325 x 320 bed)
 */

include <all-racks-config.scad>

// =========================================
// ASSEMBLY
// =========================================

/**
 * Complete Rack Assembly
 *
 * BOUNDING BOX: [0, 0, 0] to [264, 286.7, 200]
 */
module rack() {
    union() {
        difference() {
            union() {
                // Outer shell minus inner cavity
                difference() {
                    rounded_box(outer_width_mm, outer_height_mm, rack_depth_mm, edge_radius_mm);
                    inner_cavity();
                }

                // Front mounting rails (45-deg bevel on inner back edge)
                mounting_rail(wall_thickness_mm, "right");
                mounting_rail(outer_width_mm - wall_thickness_mm - rack_rail_width_mm, "left");

                // Back mounting rails (45-deg bevel on inner front edge)
                back_mounting_rail(wall_thickness_mm, "right");
                back_mounting_rail(outer_width_mm - wall_thickness_mm - rack_rail_width_mm, "left");

                // Zip tie towers on all interior walls
                zip_tie_towers();
            }

            // Front mounting screw holes
            mounting_holes(mount_hole_x_left_mm);
            mounting_holes(mount_hole_x_right_mm);

            // Back mounting screw holes
            back_mounting_holes(mount_hole_x_left_mm);
            back_mounting_holes(mount_hole_x_right_mm);

            // Front M6 nut traps (V bevel above)
            if (enable_nut_traps) {
                nut_traps_left();
                nut_traps_right();
            }

            // Back M6 nut traps (V bevel below)
            if (enable_nut_traps) {
                back_nut_traps_left();
                back_nut_traps_right();
            }

            // Handle cutouts
            handle_cutout(-1);
            handle_cutout(outer_width_mm - wall_thickness_mm);
        }

        // Grip bars inside handle cutouts (added back after cutout subtraction)
        grip_bar(wall_thickness_mm / 2);                            // Left wall
        grip_bar(outer_width_mm - wall_thickness_mm / 2);           // Right wall
    }
}

// =========================================
// DEBUG / VISUALIZATION
// =========================================

module assembly_colored() {
    color("DimGray", 0.9) rack();
}

module assembly_xray() {
    color("SteelBlue", 0.4) rack();
}

// =========================================
// DEFAULT RENDER
// =========================================

assembly_colored();

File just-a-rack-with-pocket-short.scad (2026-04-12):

/**
 * 10-Inch Unibody Server Rack (6U) - "Just a Rack" with USW Flex Mini Pocket
 * Prints in one piece on Bambu Labs H2D - front face down, no supports
 *
 * Includes a pocket on the right interior wall for a Ubiquiti USW Flex Mini
 * switch, with 45-degree ramp underneath for support-free printing.
 *
 * Bambu Labs H2D Build Volume (single nozzle): 325 x 320 x 325 mm
 * This model footprint: 264 x 310 mm (fits within 325 x 320 bed)
 */

include <all-racks-config.scad>

// =========================================
// USW FLEX MINI POCKET (right wall, bottom)
// =========================================

// Switch dimensions
usw_length_mm  = 107.16;       // Long side
usw_width_mm   = 70.15;        // Short side (pocket depth)
usw_height_mm  = 21.17;        // Thickness (into rack interior)

pocket_clearance_mm = 0.5;
pocket_wall_mm      = 3.0;

// Cavity dimensions (switch + clearance)
pocket_cav_x_mm = usw_height_mm + 2 * pocket_clearance_mm;     // 22.17
pocket_cav_y_mm = usw_length_mm + 2 * pocket_clearance_mm;     // 108.16
pocket_cav_z_mm = usw_width_mm  + pocket_clearance_mm;         // 70.65 (open top)

// Exterior dimensions (cavity + walls)
pocket_ext_x_mm = pocket_cav_x_mm + pocket_wall_mm;            // 25.17 (one wall on interior side)
pocket_ext_y_mm = pocket_cav_y_mm + 2 * pocket_wall_mm;        // 114.16
pocket_ext_z_mm = pocket_cav_z_mm + pocket_wall_mm;            // 73.65 (one wall on bottom, open top)

// Position: against right wall inner surface, flush with bottom, centered Z
pocket_x_mm = outer_width_mm - wall_thickness_mm - pocket_ext_x_mm;
pocket_y_mm = wall_thickness_mm;
pocket_z_mm = rack_depth_mm / 2 - pocket_ext_z_mm / 2;

module usw_pocket_solid() {
    translate([pocket_x_mm, pocket_y_mm, pocket_z_mm])
        cube([pocket_ext_x_mm, pocket_ext_y_mm, pocket_ext_z_mm]);
}

module usw_pocket_cavity() {
    // Main cavity (open top)
    translate([pocket_x_mm + pocket_wall_mm,
               pocket_y_mm + pocket_wall_mm,
               pocket_z_mm + pocket_wall_mm])
        cube([pocket_cav_x_mm,
              pocket_cav_y_mm,
              pocket_cav_z_mm + 1]);    // +1 extends through open top

    // Bottom opening (-Z side): 5mm inset on each Y side, 1mm inset on X front/back
    // Extends through pocket bottom wall AND the ramp below
    translate([pocket_x_mm + pocket_wall_mm + 1,
               pocket_y_mm + pocket_wall_mm + 5,
               pocket_z_mm - pocket_ext_x_mm - 1])
        cube([pocket_cav_x_mm - 2,
              pocket_cav_y_mm - 10,
              pocket_ext_x_mm + pocket_wall_mm + 2]);

    // Triangle cutout through pocket interior wall only (facing rack interior)
    // Base at bottom of ramp, apex 30mm above cavity floor
    // Limited to the 3mm pocket wall so the rack outer wall stays solid
    hull() {
        // Base: pocket interior wall width at bottom of pocket wall
        translate([pocket_x_mm - 1,
                   pocket_y_mm + pocket_wall_mm + 5,
                   pocket_z_mm - pocket_ext_x_mm - 1 + 20])
            cube([pocket_wall_mm + 2, pocket_cav_y_mm - 10, 0.01]);
        // Apex: center point 50mm above cavity floor
        translate([pocket_x_mm - 1,
                   pocket_y_mm + pocket_ext_y_mm / 2 - 0.005,
                   pocket_z_mm + pocket_wall_mm + 50])
            cube([pocket_wall_mm + 2, 0.01, 0.01]);
    }
}

// 45-degree ramp under pocket for support-free printing
// Slopes from full pocket width at z=pocket_z to wall surface at z=pocket_z - pocket_ext_x
module usw_pocket_ramp() {
    hull() {
        // Full bottom face of pocket
        translate([pocket_x_mm, pocket_y_mm, pocket_z_mm])
            cube([pocket_ext_x_mm, pocket_ext_y_mm, 0.01]);
        // Line at wall surface, one pocket_ext_x below
        translate([outer_width_mm - wall_thickness_mm - 0.01,
                   pocket_y_mm,
                   pocket_z_mm - pocket_ext_x_mm])
            cube([0.01, pocket_ext_y_mm, 0.01]);
    }
}

// =========================================
// CUSTOM ZIP TIE TOWER LAYOUT
// =========================================

/**
 * Modified tower placement for rack with pocket:
 *   - Left wall: all 4 rows x 3 cols (unchanged)
 *   - Right wall: top 2 rows only (Y3, Y4) - bottom rows replaced by pocket
 *   - Top wall: unchanged (5 cols x 4 rows)
 *   - Bottom wall: rightmost 3 cols removed, remaining 2 shifted 50mm left
 */
module rack_towers() {
    // Side wall Y positions
    sy1 = wall_thickness_mm + 20;
    sy3 = handle_y_center_mm - handle_slot_width_mm / 2 - 20;
    sy2 = (sy1 + sy3) / 2;
    sy4 = outer_height_mm - wall_thickness_mm - 10;
    side_y = [sy1, sy2, sy3, sy4];

    // Side wall Z positions (3 cols between rails)
    sz_min = rail_depth_mm;
    sz_max = rack_depth_mm - rail_depth_mm;
    side_z = [for (i = [1:3]) sz_min + (sz_max - sz_min) / 4 * i];

    // Top/bottom Z positions (4 rows)
    tb_z1 = 20;
    tb_z4 = rack_depth_mm - 20;
    tb_z = [for (i = [0:3]) tb_z1 + (tb_z4 - tb_z1) / 3 * i];

    // Top/bottom X positions (5 cols between rail inner faces)
    tx_min = rail_left_inner_x_mm;
    tx_max = rail_right_inner_x_mm;
    tb_x = [for (i = [1:5]) tx_min + (tx_max - tx_min) / 6 * i];

    // --- Left wall: all 4 rows x 3 cols ---
    for (iy = [0:3]) {
        for (iz = [0:2]) {
            translate([wall_thickness_mm, side_y[iy], side_z[iz]])
                rotate([0, 90, 0]) zip_tie_tower();
        }
    }

    // --- Right wall: top 2 rows only (skip bottom 2 for pocket) ---
    for (iy = [2:3]) {
        for (iz = [0:2]) {
            translate([outer_width_mm - wall_thickness_mm, side_y[iy], side_z[iz]])
                rotate([0, -90, 0]) zip_tie_tower();
        }
    }

    // --- Right wall: towers near pocket ---
    pocket_tower_spacing = 25;
    pocket_tower_z_back  = pocket_z_mm + pocket_ext_z_mm + pocket_tower_spacing;
    pocket_tower_z_front = pocket_z_mm - pocket_tower_spacing;
    pocket_tower_y = [for (i = [1:3])
        pocket_y_mm + pocket_ext_y_mm / 4 * i];

    // 3 towers behind pocket opening
    for (iy = [0:2]) {
        translate([outer_width_mm - wall_thickness_mm, pocket_tower_y[iy], pocket_tower_z_back])
            rotate([0, -90, 0]) zip_tie_tower();
    }


    // --- Top wall: unchanged ---
    for (ix = [0:4]) {
        for (iz = [0:3]) {
            translate([tb_x[ix], outer_height_mm - wall_thickness_mm, tb_z[iz]])
                rotate([90, 0, 0]) zip_tie_tower();
        }
    }

    // --- Bottom wall: leftmost 2 cols shifted 50mm left, rightmost 3 removed ---
    for (ix = [0:1]) {
        for (iz = [0:3]) {
            translate([tb_x[ix] - 50, wall_thickness_mm, tb_z[iz]])
                rotate([-90, 0, 0]) zip_tie_tower();
        }
    }
}

// =========================================
// ASSEMBLY
// =========================================

/**
 * Complete Rack Assembly with USW Flex Mini Pocket
 *
 * BOUNDING BOX: [0, 0, 0] to [264, 310, 200]
 */
module rack() {
    union() {
        difference() {
            union() {
                // Outer shell minus inner cavity
                difference() {
                    rounded_box(outer_width_mm, outer_height_mm, rack_depth_mm, edge_radius_mm);
                    inner_cavity();
                }

                // Front mounting rails (45-deg bevel on inner back edge)
                mounting_rail(wall_thickness_mm, "right");
                mounting_rail(outer_width_mm - wall_thickness_mm - rack_rail_width_mm, "left");

                // Back mounting rails (45-deg bevel on inner front edge)
                back_mounting_rail(wall_thickness_mm, "right");
                back_mounting_rail(outer_width_mm - wall_thickness_mm - rack_rail_width_mm, "left");

                // Custom zip tie tower layout
                rack_towers();

                // USW Flex Mini pocket + ramp
                usw_pocket_solid();
                usw_pocket_ramp();
            }

            // Front mounting screw holes
            mounting_holes(mount_hole_x_left_mm);
            mounting_holes(mount_hole_x_right_mm);

            // Back mounting screw holes
            back_mounting_holes(mount_hole_x_left_mm);
            back_mounting_holes(mount_hole_x_right_mm);

            // Front M6 nut traps (V bevel above)
            if (enable_nut_traps) {
                nut_traps_left();
                nut_traps_right();
            }

            // Back M6 nut traps (V bevel below)
            if (enable_nut_traps) {
                back_nut_traps_left();
                back_nut_traps_right();
            }

            // Handle cutouts
            handle_cutout(-1);
            handle_cutout(outer_width_mm - wall_thickness_mm);

            // USW Flex Mini pocket cavity (also clears any overlapping towers)
            usw_pocket_cavity();
        }
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

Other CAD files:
rack-with-cubbies-with-pocket.scad
rack-with-cubbies.scad
waveshare-7inch-lcd-case-dual-landscape-stacked.scad
waveshare-7inch-lcd-case-dual-portrait-side-by-side.scad
waveshare-7inch-lcd-case-landscape.scad
waveshare-7inch-lcd-case-portrait.scad
waveshare-7inch-lcd-panel.scad

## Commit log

2026-04-04 Initial commit: 6U unibody 10-inch server rack for Bambu Labs H2D
    Parametric OpenSCAD design for a unibody 10-inch server rack that prints
    in one piece, front-face-down, with no supports. Features EIA-310 mounting
    holes, 5mm walls, rounded edges, and side handle cutouts.
    [rack.scad]
2026-04-05 Replace rack.scad with two new designs: just-a-rack and rack-with-cubbies
    Split the original 6U rack into two standalone designs with significant
    upgrades: M6 nut traps with diamond bevels, 18mm grip bars, filleted
    handle cutouts, rail margins, and deeper 30mm rails. The cubbies variant
    adds a 55mm side extension with shelves every 4 inches.
    [just-a-rack.scad, rack-with-cubbies.scad, rack.scad]
2026-04-12 Split rack designs into 4 variants: with and without USW pocket
    - just-a-rack.scad: clean 6U rack, no pocket
    - just-a-rack-with-pocket.scad: 6U rack with USW Flex Mini pocket
    - rack-with-cubbies.scad: 6U rack with side cubbies, no pocket
    - rack-with-cubbies-with-pocket.scad: cubbies + USW pocket on divider wall
    Also adds shared config (all-racks-config.scad), Waveshare LCD panel
    design, and updates README with all 4 design entries.
    Pocket triangle cutout limited to interior wall only for clean printing.
    [all-racks-config.scad, just-a-rack-with-pocket.scad, just-a-rack.scad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]
2026-04-26 Resize and offset LCD window cutout
    Increase window to 156x87mm and shift left 4mm, up 3mm via new
    lcd_window_offset_x_mm / lcd_window_offset_y_mm parameters.
    [waveshare-7inch-lcd-panel.scad]
2026-05-10 Add CI pipeline, update README with missing designs, fix build scripts
    Adds .github/workflows/release.yml to build all parts and publish a
    rolling Latest Build GitHub release on every push to main.
    Updates README to include the three previously undocumented designs:
    just-a-rack-short, just-a-rack-with-pocket-short, and
    waveshare-7inch-lcd-panel.
    Updates build.sh and generate.bat to skip all-racks-config.scad (shared
    config file, not a standalone printable part).
    Also stages the new and recently modified SCAD files.
    [just-a-rack-short.scad, just-a-rack-with-pocket-short.scad, waveshare-7inch-lcd-panel.scad]
2026-07-12 Add adjustable Waveshare LCD Pi cases
    [waveshare-7inch-lcd-case-dual-landscape-stacked.scad, waveshare-7inch-lcd-case-dual-portrait-side-by-side.scad, waveshare-7inch-lcd-case-landscape.scad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]
2026-07-12 Redesign LCD cases as closed enclosures
    [waveshare-7inch-lcd-case-dual-landscape-stacked.scad, waveshare-7inch-lcd-case-dual-portrait-side-by-side.scad, waveshare-7inch-lcd-case-landscape.scad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]
